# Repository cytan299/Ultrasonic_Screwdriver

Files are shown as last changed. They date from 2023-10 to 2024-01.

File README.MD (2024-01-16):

# Ultrasonic Screwdriver -- An improved DIY homemade Doctor Who Sonic Screwdriver

by C.Y. Tan 2023 and 2024

The Ultrasonic Screwdriver is an improved DIY homemade Doctor Who Sonic
Screwdrivers. I made this screwdriver that does actual, real
measurements rather than simply performing as a prop.

Ultrasonic Scewdriver

In my design, the heart of the Ultrasonic Screwdriver is the [ESP32-S3
reverse TFT Feather](https://www.adafruit.com/product/5691) made by
Adafruit. The ESP32-S3 contains dual cores running at 240 MHz with 4
MB Flash and 2 MB PSRAM of memory. Adafruit also added a colour 1.14
inch TFT display with 240x130 pixels. This makes the ESP32-S3 reverse
TFT Feather the ideal platform for the Ultrasonic Screwdriver because
it has enough horsepower and I/O to host multiple devices.  The
devices that the Ultrasonic Screwdriver contains are as follows:

* **Ultrasonic** range finder which makes it possible for me to call
  my screwdriver the Ultrasonic. The ultrasonic range finder is made
  by [MaxBotix](https://www.adafruit.com/product/983).
* **Torch** to light up the darkness or _alien dungeons_. Torch uses the [Neopixel 12x5050
  RGBW LEDs](https://www.adafruit.com/product/2851).
* **Thermal camera** which measures the temperature of objects using
  IR. The thermal camera is made by
  [Melexis](https://www.adafruit.com/product/4469). _It's great for
  scanning hot alien devices_.
* **WIFI** scanner that uses the built in [WIFI circuitry](https://learn.adafruit.com/esp32-s3-reverse-tft-feather/wifi-test) in the
  ESP32-S3 to _scan the air for alien radio transmissions_.
* **IR TV transmitter** uses the [RMT (remote control
  transceiver)](https://docs.espressif.com/projects/esp-idf/en/latest/esp32/api-reference/peripherals/rmt.html)
   built into the ESP32-S3 for controlling the TV using NEC codes. _Or
  to open alien doors_.
* **Sound** ESP32-S3 sends sound bytes to the [I2S 3W class D
  amplifer](https://www.adafruit.com/product/3006) for sound
  generation.
* **Ultrasonic zapper** combines the ultrasonic range finder that
  transmits ultrasound at 42 kHz in free-run mode, the Neopixel Ring
  flashing rainbow colours and the Ultrasound Screwdriver sound to
  scare animals or _blow up Daleks_ :)
  
Like many Doctor Who sonic screwdrivers, the Ultrasonic Screwdriver can
also be flicked or slid open. Unlike Doctor Who sonic screwdrivers that
_psychically_ connects with the Doctor, my rendition reveals the user
screen and control buttons after it is opened.

The only shortcoming of the Ultrasonic Screwdriver is that it does not
function as a screwdriver :)

And for completeness, I have also made a Charging Stand for the
Ultrasonic Screwdriver. It's a nice stand for the Ultrasonic
Screwdriver to rest and recharge.

Note: As of Jan 2024, the charging circuit has been upgraded to v2
which allows the Ultrasonic Screwdriver to be charged by simply
inserting it into the Charging Stand. All relevant files have been
updated to include this upgrade.

## Directory structure

* **openscad** The program _sonic_case.scad_ that generates the STL files for making the
  shell of the Ultrasonic Screwdriver.
* **STL** The STL files that were generated by the
  _sonic_case.scad_ and _sonic_stand.scad_. These files are used to 3D
  print the sonic shell and its charging stand using
slicer programs like [Ultimaker CURA](https://ultimaker.com/software/ultimaker-cura/).
* **ultrasonic_screwdriver** contains the ESP32-S3 source code that is
  compiled by the [Arduino IDE](https://www.arduino.cc/en/software)
  and programmed  into the ESP32-S3.
* **laser_cut** contains my unique badge and top plate that has
  decorations written in
  [Gallifreyan](https://shermansplanet.com/gallifreyan/guide.pdf).
* **circuit** The Ultrasonic Screwdriver and charging stand connection circuits.
* **howto** contains the build guide.	
* **bom** contains the bill of materials spreadsheet that
partially lists the parts that I had used to build the screwdriver.
* **pics** contains photos used for describing this repository.

## Movie

A summary of the features of the Ultrasonic Screwdriver can be found
on [youtube](https://youtu.be/zgtzh80xZCQ).

## Support

All the software have been successfully compiled with Arduino IDE 2.2.1.

This is unsupported software and hardware. Build at your own peril! :)

You can submit questions or bug reports using the
[issues](https://github.com/cytan299/Ultrasonic_Screwdriver/issues) tab 
and then clicking on **New Issue**.

Have fun!

## Copyright

All the software, documentation, hardware designs that I have written is
copyright 2023 C.Y. Tan.

All software is released under GPLv3.

All documentation is released under Creative Commons
Attribution-ShareAlike 3.0 Unported License or GNU Free
Documentation License, Version 1.3

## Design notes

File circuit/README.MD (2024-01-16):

# Ultrasonic Screwdriver schematic diagram

This is the schematic diagrams of the Ultrasonic Screwdriver and
charging circuit in Fritzing-like format. The [bill of materials
(BOM)](https://github.com/cytan299/Ultrasonic_Screwdriver/tree/main/bom)
file contains the parts that were used.

## Upgrade to v2

In v1, it is very clumsy to charge the Ultrasonic Screwdriver because
the bottom cover has to be unscrewed to reveal a charging plug. The
plug is then attached to the Charging Stand's socket for charging.  In
the upgraded version 2, the Ultrasonic Screwdriver can be charged by
inserting it into the Charging Stand.

These diagrams contain both the v1 and v2 circuits.

## Copyright

The schematic design of the Ultrasonic Screwdriver and charging
circuit is copyright 2023 C.Y. Tan and is released under under
Creative Commons Attribution-ShareAlike 3.0 Unported License. To view
a copy of this license, visit
http://creativecommons.org/licenses/by-sa/3.0/

The copyright for many of the parts used in this Fritzing-like schematic is held by Adafruit. Adafruit released the Adafruit Fritzing Libary under CC Attribution Share-Alike.

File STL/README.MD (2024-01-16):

# Parts for 3D printer

The subdirectories
* **sonic_case** contains the STL files that form the outer shell of
  the Ultrasonic screwdriver.
* **sonic_stand** contains the STL files that form the charging test stand.

## Copyright

All the STL files in subdirectories _sonic_case_ and _sonic_stand_ are
released under Creative Commons Attribution-ShareAlike 3.0 Unported
License.

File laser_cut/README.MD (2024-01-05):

# Laser cut parts

The subdirectories
* **badge** contains my unique badge that is mounted on the
  Ultrasonic screwdriver and its charging test stand.
* **top_plate** contains my unique top plate design that is mounted at
  the top of the charging test stand.

## Copyright

Both the _badge_single_v2.svg_ and _top_plate_ponoko1.svg_ are
released under Creative Commons Attribution-ShareAlike 3.0 Unported
License.

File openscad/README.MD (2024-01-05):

# OpenScad files

These [OpenScad](https://openscad.org/) files stored here generated
all the
[STL](https://github.com/cytan299/Ultrasonic_Screwdriver/tree/main/STL)
files that are loaded into a slicer program like the [Ultimaker
CURA](https://ultimaker.com/software/ultimaker-cura/) for 3D printing.

## Files
* **sonic_case.scad** The main source file that generates nearly all parts of the Ultrasonic Screwdriver case.
* **push_button.scad** The pushbutton that releases the spring to allow the inner case structure of the Ultrasonic Screwdriver to slide.
* **spring.scad** is the spring mechanism that holds the inner case
  structure open when it is extended out of the outer case.
* **sonic_stand.scad** is the source file that generates the
  Ultrasonic Screwdriver charging stand.
* **libscrew.scad** is the OpenScad [screw library](https://www.thingiverse.com/thing:1686322) written by R. Colyer. It is uploaded here for convenience.

## Copyright

All the software that I have written is copyright 2023 C.Y. Tan.

All software is released under GPLv3

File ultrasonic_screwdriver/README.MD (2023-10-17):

# ESP32 Ultrasonic Screwdriver Software

by C.Y. Tan 2023

This is the source code for the ESP32-S3 Ultrasonic Screwdriver
software. This software has been successfully compiled under Arduino
IDE 2.2.1. Instructions for enabling the Arduino IDE for compiling the
ESP32 can be found
[here](https://learn.adafruit.com/esp32-s3-reverse-tft-feather/arduino-ide-setup-2). This
program utilizes the dual core of the ESP32-S3 by splitting the tasks
between a master and a slave on each CPU. Communications between
master and slave is with [FreeTOS](https://docs.espressif.com/projects/esp-idf/en/latest/esp32/api-reference/system/freertos.html):
* **ultrasonic_screwdriver.ino** is the master program. It directly
controls
    * **Menu** system and user input.
	* **TV** IR control
    * **Sound** of the Ultrasonic Screwdriver.
	
From the user selection of the menu items, it sends messages to the slave program. The
tasks that the slave program executes are listed  below:
* **slave.ino** is the slave that listens to the master program and
  executes its commands for the following devices:
    * **Torch** on/off
	* **Thermal camera** display
	* **Sonic** ultrasound range finder display
	* **WIFI** scan and display
	* **Battery status** display.
	* **About** copyright and version display.
	
The following are the support programs used by both
_ultrasonic_screwdriver.ino_ and _slave.ino_:
* **IR_TX.cpp** and **IR_TX.hpp** contains the IR transmitter class that
  utilizes the ESP32-S3 onboard RMT (remote control transceiver) to
  produce NEC codes for TV control. The code here is for VIZIO TVs.
  Other codes for your TV is easily found in this
  [database](https://github.com/probonopd/irdb/tree/master).
* **audio.io** is the audio program that contains the Ultrasonic
  Screwdriver sound bytes that were created by me.
  
The following are programs that have been copied from the web and are
copyright by their respective authors. Here are the two programs that
are used:
* **ring_meter.ino** by Bodmer and is released under _CC BY-NC-SA 4.0
  Deed_ license. It is used for displaying the ultrasonic range finder
  results.
* **wheel.ino** by Adafruit and is released under _LGPL-3.0_
license. It is used for displaying the rainbow colours on the NeoPixel
  ring.

## Copyright

All the software that I have written is copyright 2023 C.Y. Tan.

All software is released under GPLv3.

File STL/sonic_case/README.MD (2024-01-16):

# Ultrasonic Screwdriver Case STL files

These STL files were created with [OpenScad](https://openscad.org/) from
the source code in
[openscad](https://github.com/cytan299/Ultrasonic_Screwdriver/tree/main/openscad). These
files are loaded into a slicer program like the [Ultimaker
CURA](https://ultimaker.com/software/ultimaker-cura/) for 3D printing.

## Infill

It is interesting that the best setting that I have found for the infill is
zigzag and not cubic. I wanted a strong shell and so I had to set the
fill fraction to be 50%. You should check that zigzag and 50% fill
works for you by examining the generated cross sections in your slicer
program.

## Upgrade to v2

In v1, the Ultrasonic Screwdriver is charged by unscrewing its base to
reveal a charging plug. The plug is then attached to the Charging
Stand's socket for charging.

In the upgraded version 2, the Ultrasonic Screwdriver can be charged
by inserting it into the Charging Stand. This upgrade will require the
following new STL files:

* **slip_adapter_v2.stl** The slip adapter that has space for the spring
  connector and the alignment recesses.
* **slip_cap_v2.stl** The slip cap that covers the bottom of the _slip
adapter v2_.

## Copyright

All the software that I have written is copyright 2023 C.Y. Tan.

All software is released under GPLv3.

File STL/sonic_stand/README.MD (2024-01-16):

# Ultrasonic Screwdriver Charging Stand STL files

These STL files were created with [OpenScad](https://openscad.org/)
from the source code in
[openscad](https://github.com/cytan299/Ultrasonic_Screwdriver/tree/main/openscad/sonic_stand.scad). These
files are loaded into a slicer program like the [Ultimaker
CURA](https://ultimaker.com/software/ultimaker-cura/) for 3D printing.

## Infill

Only top_plate_with_laser_plate.stl is printed with 10% gyroid with
transparent PLA. The remaining parts used an infill of 20% cubic. 

## Upgrade to v2

In v1, the Ultrasonic Screwdriver is charged by unscrewing its base to
reveal a charging plug. The plug is then attached to the Charging
Stand's socket for charging. 

In the upgraded version 2, the Ultrasonic Screwdriver can be charged
by inserting it into the Charging Stand. This upgrade will require the
following new STL file for the charging stand:

* **alignment_pegs.stl** This file contains the alignment pegs and the
  recess for the spring connector.

## Laser cut decoration

The laser cut decoration is in [laser_cut](https://github.com/cytan299/Ultrasonic_Screwdriver/tree/main/laser_cut)

## Copyright

All the software that I have written is copyright 2023 C.Y. Tan.

All software is released under GPLv3.

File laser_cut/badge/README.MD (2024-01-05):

# Badge

The file
* **badge_single_v2.svg** contains my unique badge design written in
  [Gallifreyan](https://shermansplanet.com/gallifreyan/guide.pdf) that
  is laser cut and mounted to the front of the Ultrasonic 
  Screwdriver and the charging stand.
  
The _badge_single_v2.svg_ can be sent to a laser cutting vendor
like [Ponoko](https://www.ponoko.com/) for laser cutting. The material that I had used is 1.5 mm thick
_Brushed Copper on Black Two Color Acrylic_. 

You can personalize the badge by modifying the svg file and
then laser cutting it.

## Copyright

The _badge_single_v2.svg_ is released under Creative Commons
Attribution-ShareAlike 3.0 Unported License.

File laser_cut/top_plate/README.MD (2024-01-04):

# Top plate

The file
* **top_plate_ponoko1.svg** contains my unique top plate design written in
  [Gallifreyan](https://shermansplanet.com/gallifreyan/guide.pdf) that
  is laser cut and mounted to the top of the Ultrasonic
  Screwdriver charging stand.
  
The _top_plate_ponoko1.svg_ can be sent to a laser cutting vendor
like [Ponoko](https://www.ponoko.com/) for laser cutting. The material
that I had used is the 0.5 mm copper on black adhesive-backed plastic.

You can personalize the badge by modifying the svg file and
then laser cutting it.

## Copyright

The _top_plate_ponoko1.svg_ is released under Creative Commons
Attribution-ShareAlike 3.0 Unported License.

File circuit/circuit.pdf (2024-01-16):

100Ω

IR diode
CQY37N

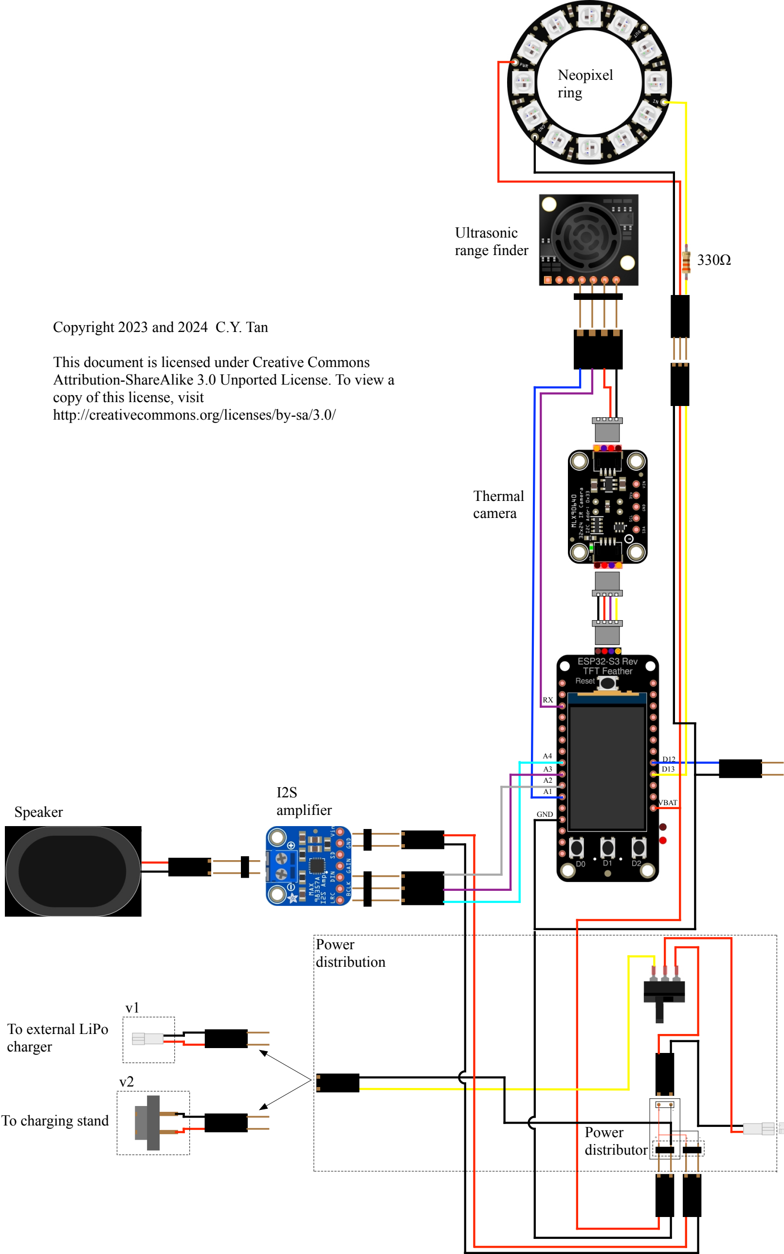
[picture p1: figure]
Neopixel ring; Ultrasonic range finder; Thermal camera; I2S amplifier; To external LiPo charger; Power distribution; GND; VBAT; Speaker; Power distributor; Copyright 2023 and 2024 C.Y. Tan; copy of this license, visit http://creativecommons.org/licenses/by-sa/3.0/; To charging stand

This document is licensed under Creative Commons Attribution-ShareAlike 3.0 Unported License. To view a

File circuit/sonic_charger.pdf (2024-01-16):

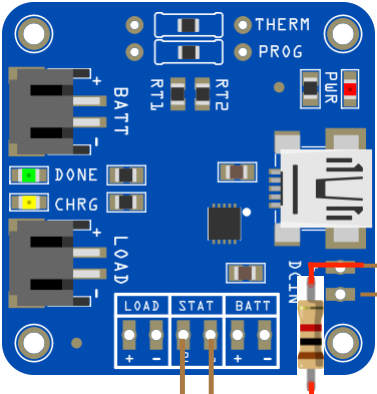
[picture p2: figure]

Red/Green LED
Common Anode

2.1 mm
power jack,
5 V in

Copyright 2023 and 2024 C.Y. Tan

This document is licensed under Creative Commons Attribution-ShareAlike 3.0 Unported License. To view a copy of this license, visit http://creativecommons.org/licenses/by-sa/3.0/

Adafruit LiIon/LiPoly
charger 1.2 V. Part
ID: 259

To ultrasonic
screwdriver

v1

v2

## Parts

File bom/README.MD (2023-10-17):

# Partial List of Materials

The bill of materials (bom) spreadsheet that I have uploaded here is
only a partial list. I have only listed the major parts that I had
ordered from both [Adafruit](https://www.adafruit.com) and
[Amazon](https://www.amazon.com). 

The parts that are missing are:
* **Paints** I did not list the paints that I had used because that's really up to
you how you'd want to paint it. 
* **3D filaments** I also did not list the 3D filaments that I had used. It's your
preference what you'll use for your 3D printer. 
    * For your reference, for the "clear" cover, I printed it with
      _SUNLU clear PLA filament 1.75 mm_. 
* **Sundries** Other sundries like sandpaper, masking tape etc. are also not included.

The bom.ods file is readable using [LibreOffice Calc](http://www.libreoffice.org).

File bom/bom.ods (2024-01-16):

Product # | Item | Quantity | Cost each | Cost | Comments | Vendor | Total Costs
5691 | ESP32-S3 reverse TFT feather | 1 | $24.95 | $24.95 |  | www.adafruit.com
3898 | Lithium Ion Polymer Battery Ideal For Feathers - 3.7V 400mAh | 1 | $6.95 | $6.95 |  |  | $245.48
4469 | Adafruit MLX90640 24x32 IR Thermal Camera Breakout (110 Degree FoV) | 1 | $74.95 | $74.95
983 | Maxbotix Ultrasonic Rangefinder - HRLV-EZ0 (HRLV-EZ0) | 1 | $36.50 | $36.50
3923 | Mini Oval Speaker - 8 Ohm 1 Watt | 1 | $1.95 | $1.95
1609 | Adafruit Perma-Proto Half-sized Breadboard PCB - Single | 1 | $0.00 | $0.00 | Free
2851 | Neopixel ring 12x505 RGBW leds | 1 | $9.50 | $9.50
3006 | I2S class D amplifier breakout | 1 | $5.95 | $5.95
259 | USB LiIon/LiPoly charger | 1 | $12.50 | $12.50
816 | 3x4 right angle male header | 1 | $2.95 | $2.95
1131 | JST-PH battery extension cable – 500 mm | 2 | $1.95 | $3.90
 | MEIYYJ 10 kinds of small multi-purpose M1 M1.2 M1.4 M1.7 Philips head micro self tapping electronic screws assortment | 1 | $6.99 | $6.99 |  | www.amazon.com
 | Glarks 635 pieces connector housing male/female connector 0.1” pitch pin headers etc. | 1 | $12.98 | $12.98
 | 150 pieces 3 pin 2 position 1P2T SPDT vertical micro slide switch 0.5 A 50V DC | 1 | $12.98 | $12.98
 | I2C Qwiic Cable Kit Stemma QT Wire for SparkFun Development Boards Sensor Board Breakout Breadboard 4 Pin Sh1.0 Connector | 1 | $9.99 | $9.99
CQY37N | Emitter IR 950 nm 100 mA radial | 1 | $0.43 | $0.43 |  | www.digikey.com
 | CHANZON 100 pcs 5mm Red & Green Diffused LED Diode Lights Common Anode | 1 | $6.99 | $0.07 | Only one is needed for the charging stand | www.amazon.com
 | HiLetgo 10pcs DC Power Supply Jack Socket Female Panel Mount Connector 3-Pin 5.5 x 2.1mm | 1 | $6.09 | $0.06 | Only one is needed for the charging stand
868-22-002-00-001101 | Mill-Max STD spring loaded connector (male) | 1 | $18.03 | $18.03 | Needed for v2 upgrade | www.mouser.com
868-10-002-00-012000 | Mill-Max 4 mm pitch Housings 4 mm pitch SLH solder cup (female) | 1 | $3.85 | $3.85 | Needed for v2 upgrade

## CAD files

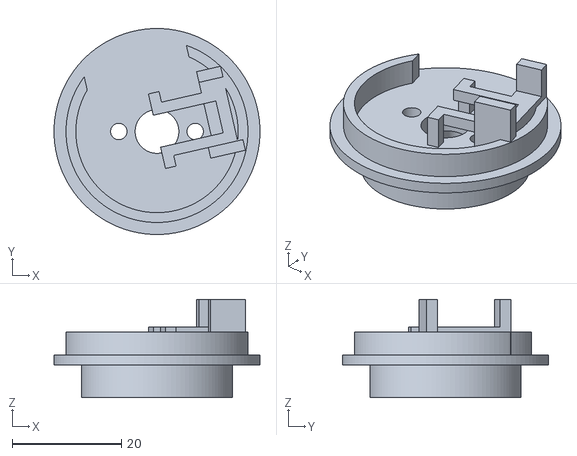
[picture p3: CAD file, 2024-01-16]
STL/sonic_case/slip_adapter_v2.stl
37.7 x 37.7 x 18.0

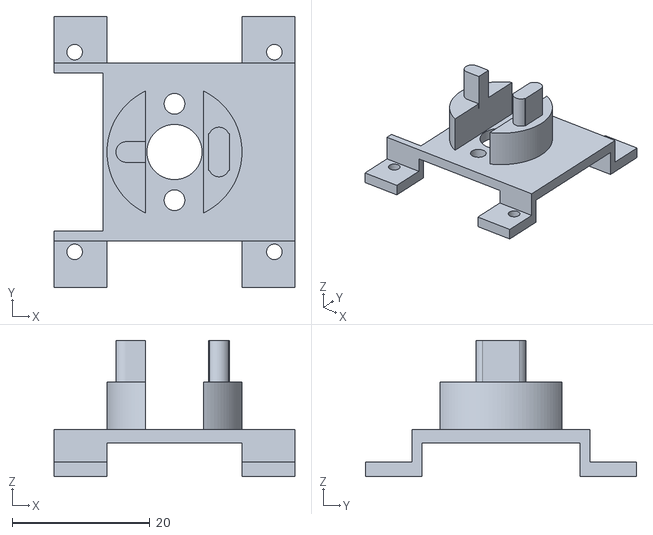
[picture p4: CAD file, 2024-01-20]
STL/sonic_stand/alignment_pegs.stl
35.0 x 39.4 x 19.8

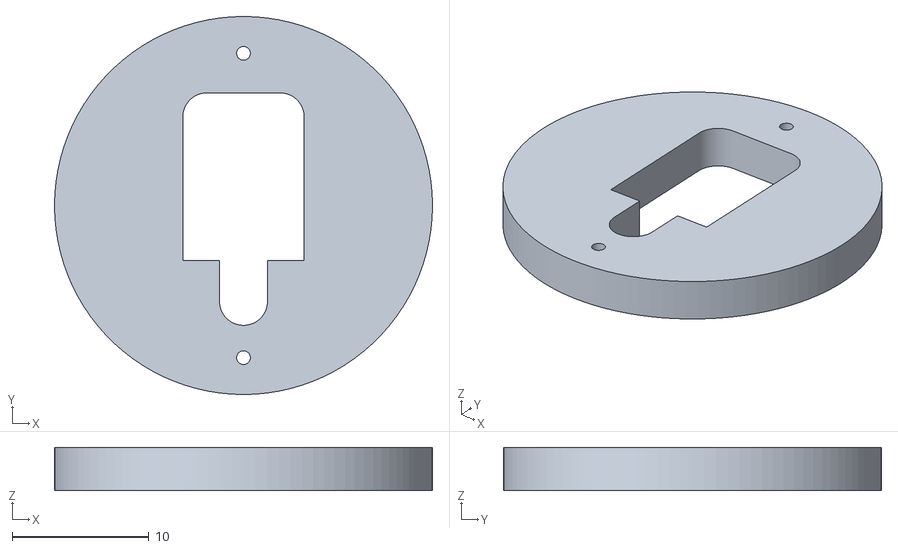
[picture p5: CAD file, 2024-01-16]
STL/sonic_case/slip_cap_v2.stl
27.6 x 27.6 x 3.15

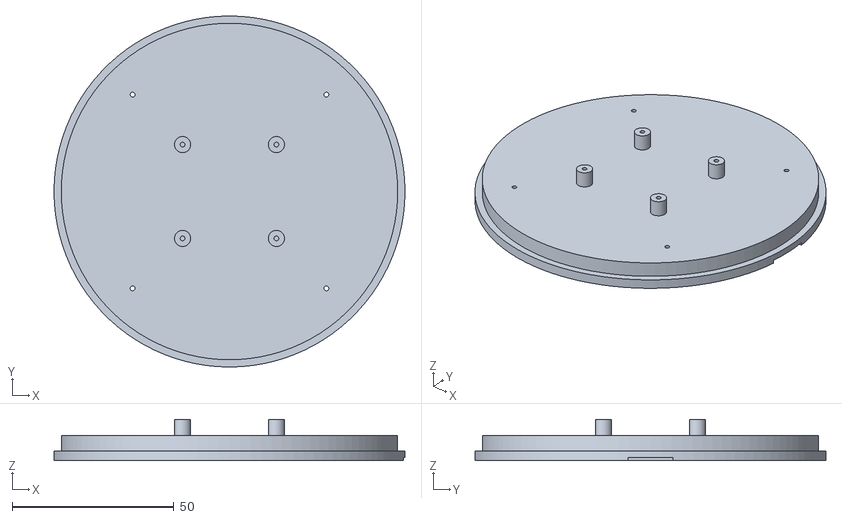
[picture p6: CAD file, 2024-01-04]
STL/sonic_stand/sonic_stand_cover.stl
108.5 x 108.5 x 12.8

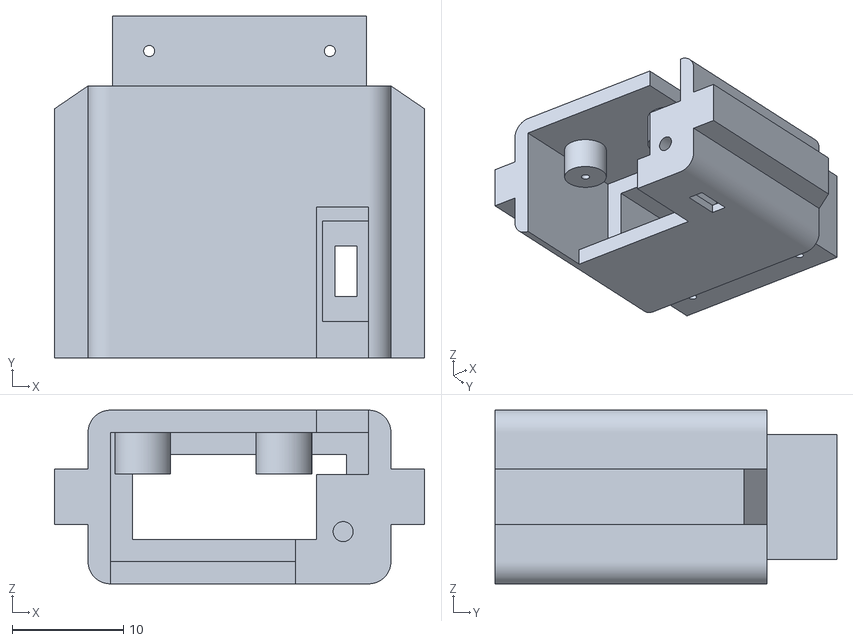
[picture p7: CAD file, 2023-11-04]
STL/sonic_case/tail_section.stl
33.3 x 30.8 x 15.6

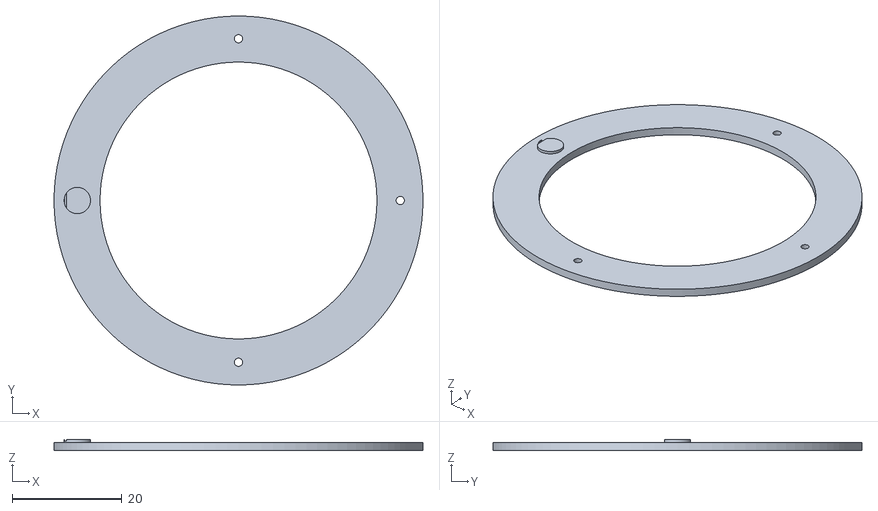
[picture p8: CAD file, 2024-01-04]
STL/sonic_stand/top_plate_with_laser_plate.stl
67.2 x 67.2 x 2.00

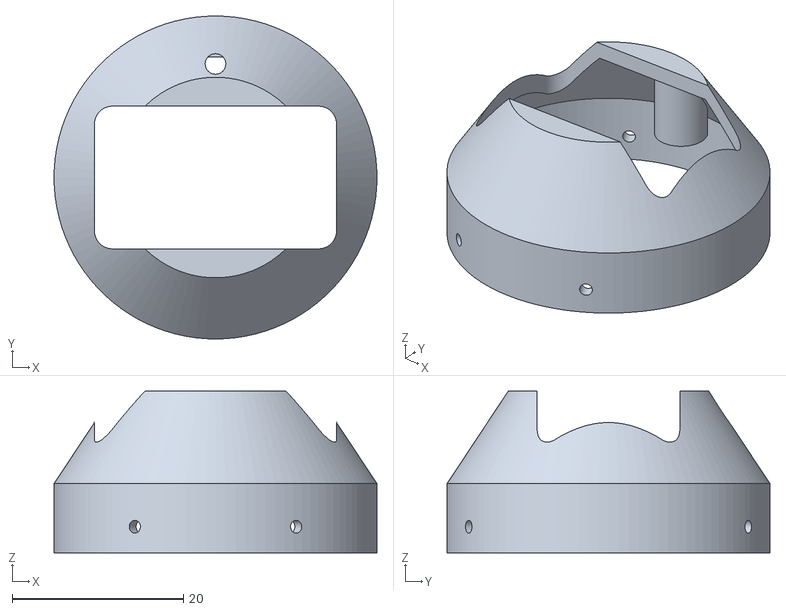
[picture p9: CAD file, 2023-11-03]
STL/sonic_case/cone.stl
37.7 x 37.7 x 18.9

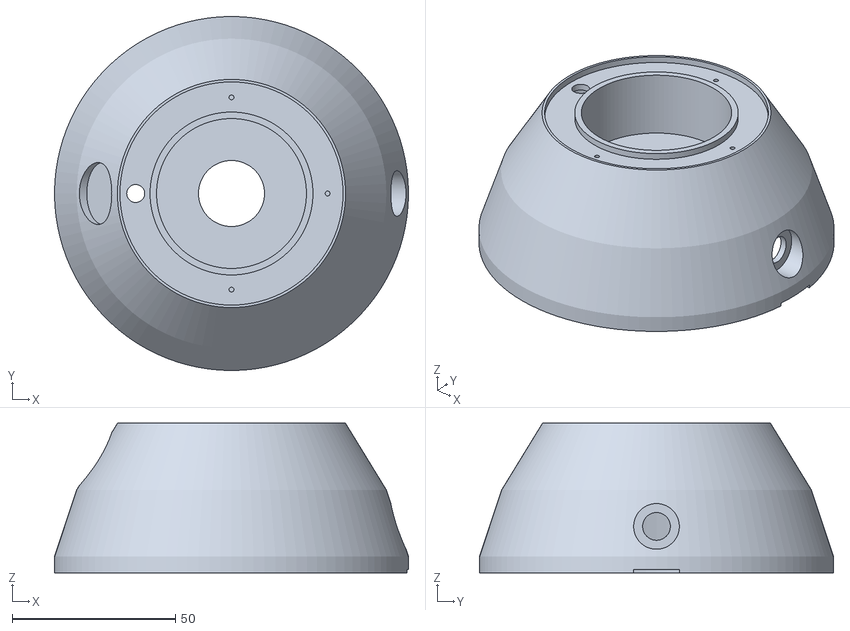
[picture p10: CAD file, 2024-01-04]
STL/sonic_stand/sonic_stand_top.stl
108.5 x 108.5 x 45.8

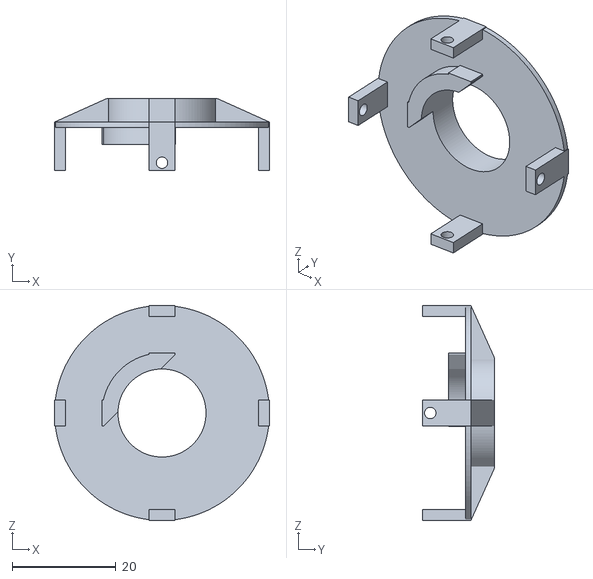
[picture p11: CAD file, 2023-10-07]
STL/sonic_case/upper_translucent_cover.stl
41.5 x 13.9 x 41.5

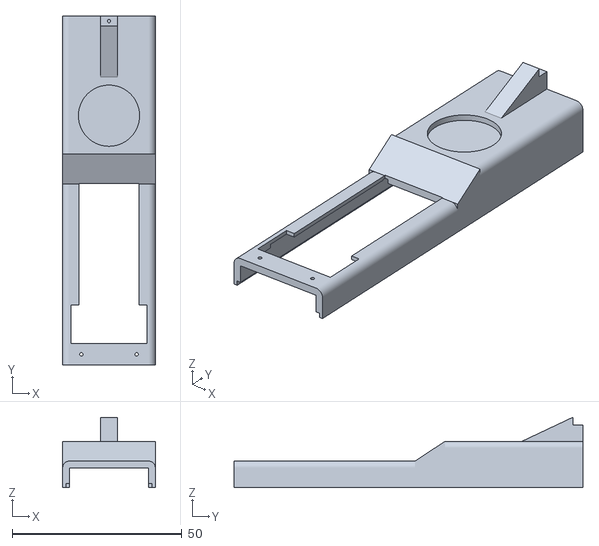
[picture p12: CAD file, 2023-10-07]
STL/sonic_case/inner_upper_case.stl
27.3 x 102.7 x 20.7

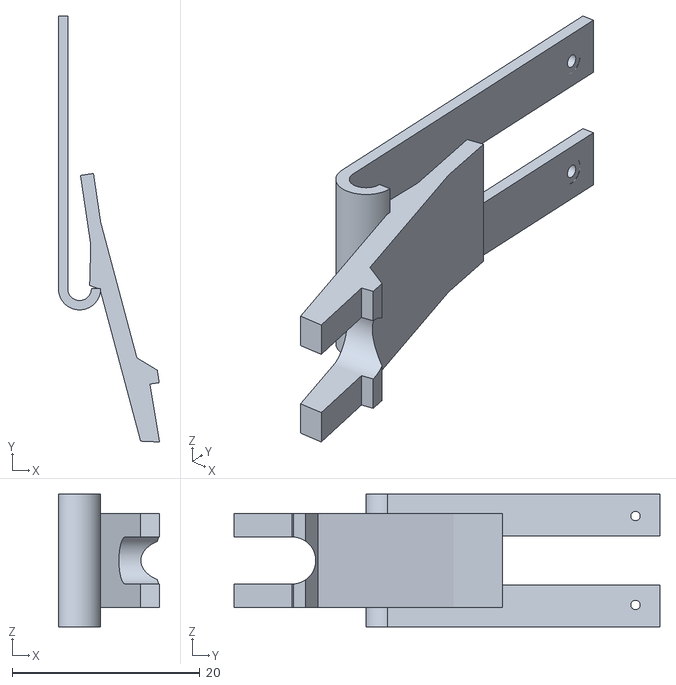
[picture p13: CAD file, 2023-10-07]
STL/sonic_case/spring.stl
10.8 x 45.4 x 14.1

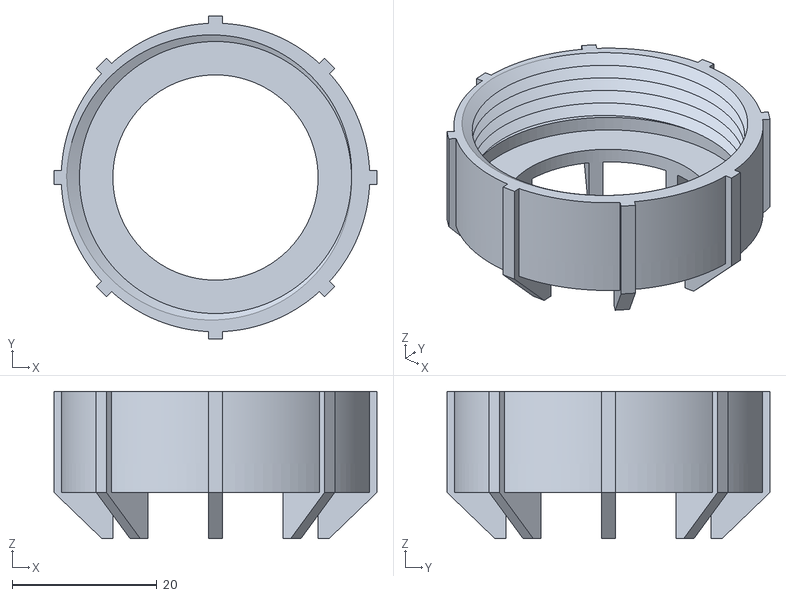
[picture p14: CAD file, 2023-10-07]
STL/sonic_case/endcap.stl
44.7 x 44.7 x 20.4

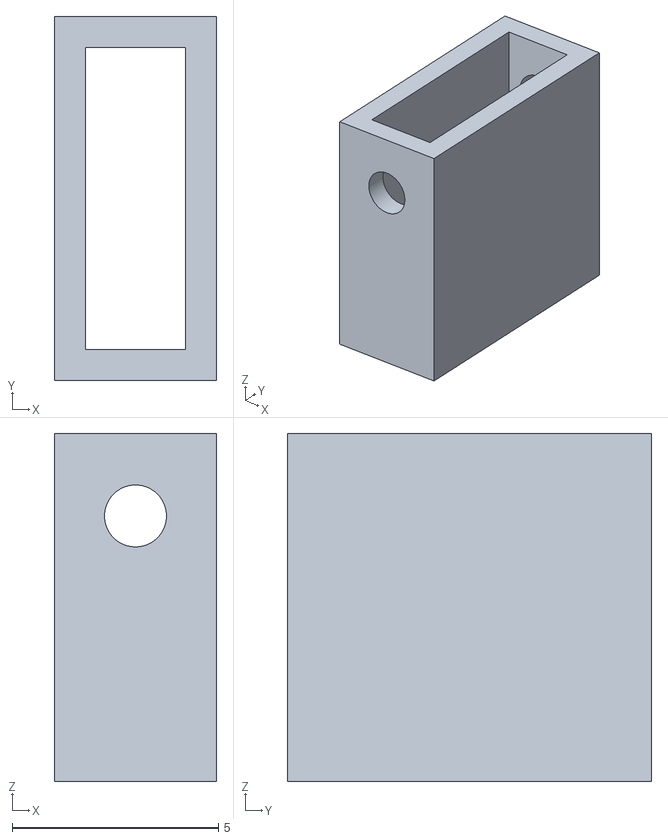
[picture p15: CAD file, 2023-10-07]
STL/sonic_case/switch_plug.stl
3.93 x 8.82 x 8.44

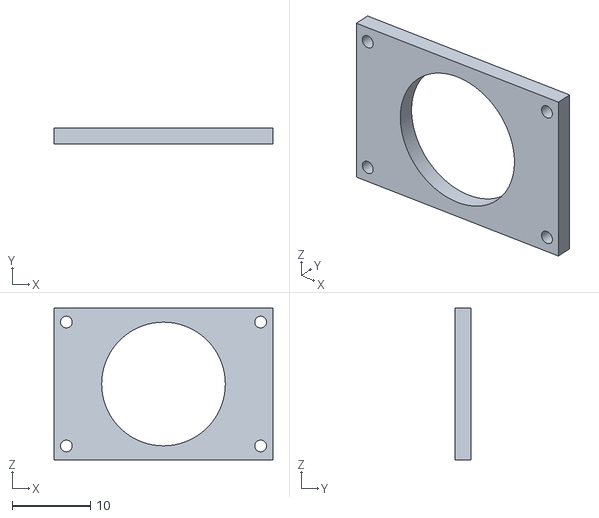
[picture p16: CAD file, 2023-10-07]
STL/sonic_case/speaker_holder.stl
28.0 x 2.00 x 19.4

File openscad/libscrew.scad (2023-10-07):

/**************************************************************/


// Created 2016-2017 by Ryan A. Colyer.
// This work is released with CC0 into the public domain.
// https://creativecommons.org/publicdomain/zero/1.0/
//
// https://www.thingiverse.com/thing:1686322
//
// v2.1


screw_resolution = 0.2;  // in mm


// Provides standard metric thread pitches.
function ThreadPitch(diameter) =
  (diameter <= 64) ?
    lookup(diameter, [
      [2, 0.4],
      [2.5, 0.45],
      [3, 0.5],
      [4, 0.7],
      [5, 0.8],
      [6, 1.0],
      [7, 1.0],
      [8, 1.25],
      [10, 1.5],
      [12, 1.75],
      [14, 2.0],
      [16, 2.0],
      [18, 2.5],
      [20, 2.5],
      [22, 2.5],
      [24, 3.0],
      [27, 3.0],
      [30, 3.5],
      [33, 3.5],
      [36, 4.0],
      [39, 4.0],
      [42, 4.5],
      [48, 5.0],
      [52, 5.0],
      [56, 5.5],
      [60, 5.5],
      [64, 6.0]
    ]) :
    diameter * 6.0 / 64;


// Provides standard metric hex head widths across the flats.
function HexAcrossFlats(diameter) =
  (diameter <= 64) ?
    lookup(diameter, [
      [2, 4],
      [2.5, 5],
      [3, 5.5],
      [3.5, 6],
      [4, 7],
      [5, 8],
      [6, 10],
      [7, 11],
      [8, 13],
      [10, 16],
      [12, 18],
      [14, 21],
      [16, 24],
      [18, 27],
      [20, 30],
      [22, 34],
      [24, 36],
      [27, 41],
      [30, 46],
      [33, 50],
      [36, 55],
      [39, 60],
      [42, 65],
      [48, 75],
      [52, 80],
      [56, 85],
      [60, 90],
      [64, 95]
    ]) :
    diameter * 95 / 64;

// Provides standard metric hex head widths across the corners.
function HexAcrossCorners(diameter) =
  HexAcrossFlats(diameter) / cos(30);


// Provides standard metric hex (Allen) drive widths across the flats.
function HexDriveAcrossFlats(diameter) =
  (diameter <= 64) ?
    lookup(diameter, [
      [2, 1.5],
      [2.5, 2],
      [3, 2.5],
      [3.5, 3],
      [4, 3],
      [5, 4],
      [6, 5],
      [7, 5],
      [8, 6],
      [10, 8],
      [12, 10],
      [14, 12],
      [16, 14],
      [18, 15],
      [20, 17],
      [22, 18],
      [24, 19],
      [27, 20],
      [30, 22],
      [33, 24],
      [36, 27],
      [39, 30],
      [42, 32],
      [48, 36],
      [52, 36],
      [56, 41],
      [60, 42],
      [64, 46]
    ]) :
    diameter * 46 / 64;

// Provides standard metric hex (Allen) drive widths across the corners.
function HexDriveAcrossCorners(diameter) =
  HexDriveAcrossFlats(diameter) / cos(30);

// Provides metric countersunk hex (Allen) drive widths across the flats.
function CountersunkDriveAcrossFlats(diameter) =
  (diameter <= 14) ?
    HexDriveAcrossFlats(HexDriveAcrossFlats(diameter)) :
    round(0.6*diameter);

// Provides metric countersunk hex (Allen) drive widths across the corners.
function CountersunkDriveAcrossCorners(diameter) =
  CountersunkDriveAcrossFlats(diameter) / cos(30);

// Provides standard metric nut thickness.
function NutThickness(diameter) =
  (diameter <= 64) ?
    lookup(diameter, [
      [2, 1.6],
      [2.5, 2],
      [3, 2.4],
      [3.5, 2.8],
      [4, 3.2],
      [5, 4.7],
      [6, 5.2],
      [7, 6.0],
      [8, 6.8],
      [10, 8.4],
      [12, 10.8],
      [14, 12.8],
      [16, 14.8],
      [18, 15.8],
      [20, 18.0],
      [22, 21.1],
      [24, 21.5],
      [27, 23.8],
      [30, 25.6],
      [33, 28.7],
      [36, 31.0],
      [42, 34],
      [48, 38],
      [56, 45],
      [64, 51]
    ]) :
    diameter * 51 / 64;


// This generates a closed polyhedron from an array of arrays of points,
// with each inner array tracing out one loop outlining the polyhedron.
// pointarrays should contain an array of N arrays each of size P outlining a
// closed manifold.  The points must obey the right-hand rule.  For example,
// looking down, the P points in the inner arrays are counter-clockwise in a
// loop, while the N point arrays increase in height.  Points in each inner
// array do not need to be equal height, but they usually should not meet or
// cross the line segments from the adjacent points in the other arrays.
// (N>=2, P>=3)
// Core triangles:
//   [j][i], [j+1][i], [j+1][(i+1)%P]
//   [j][i], [j+1][(i+1)%P], [j][(i+1)%P]
//   Then triangles are formed in a loop with the middle point of the first
//   and last array.
module ClosePoints(pointarrays) {
  function recurse_avg(arr, n=0, p=[0,0,0]) = (n>=len(arr)) ? p :
    recurse_avg(arr, n+1, p+(arr[n]-p)/(n+1));

  N = len(pointarrays);
  P = len(pointarrays[0]);
  NP = N*P;
  lastarr = pointarrays[N-1];
  midbot = recurse_avg(pointarrays[0]);
  midtop = recurse_avg(pointarrays[N-1]);

  faces_bot = [
    for (i=[0:P-1])
      [0,i+1,1+(i+1)%len(pointarrays[0])]
  ];

  loop_offset = 1;
  bot_len = loop_offset + P;

  faces_loop = [
    for (j=[0:N-2], i=[0:P-1], t=[0:1])
      [loop_offset, loop_offset, loop_offset] + (t==0 ?
      [j*P+i, (j+1)*P+i, (j+1)*P+(i+1)%P] :
      [j*P+i, (j+1)*P+(i+1)%P, j*P+(i+1)%P])
  ];

  top_offset = loop_offset + NP - P;
  midtop_offset = top_offset + P;

  faces_top = [
    for (i=[0:P-1])
      [midtop_offset,top_offset+(i+1)%P,top_offset+i]
  ];

  points = [
    for (i=[-1:NP])
      (i<0) ? midbot :
      ((i==NP) ? midtop :
      pointarrays[floor(i/P)][i%P])
  ];
  faces = concat(faces_bot, faces_loop, faces_top);

  polyhedron(points=points, faces=faces);
}



// This creates a vertical rod at the origin with external threads.  It uses
// metric standards by default.
module ScrewThread(outer_diam, height, pitch=0, tooth_angle=30, tolerance=0.4, tip_height=0, tooth_height=0, tip_min_fract=0) {

  pitch = (pitch==0) ? ThreadPitch(outer_diam) : pitch;
  tooth_height = (tooth_height==0) ? pitch : tooth_height;
  tip_min_fract = (tip_min_fract<0) ? 0 :
    ((tip_min_fract>0.9999) ? 0.9999 : tip_min_fract);

  outer_diam_cor = outer_diam + 0.25*tolerance; // Plastic shrinkage correction
  inner_diam = outer_diam - tooth_height/tan(tooth_angle);
  or = (outer_diam_cor < screw_resolution) ?
    screw_resolution/2 : outer_diam_cor / 2;
  ir = (inner_diam < screw_resolution) ? screw_resolution/2 : inner_diam / 2;
  height = (height < screw_resolution) ? screw_resolution : height;

  steps_per_loop_try = ceil(2*3.14159265359*or / screw_resolution);
  steps_per_loop = (steps_per_loop_try < 4) ? 4 : steps_per_loop_try;
  hs_ext = 3;
  hsteps = ceil(3 * height / pitch) + 2*hs_ext;

  extent = or - ir;

  tip_start = height-tip_height;
  tip_height_sc = tip_height / (1-tip_min_fract);

  tip_height_ir = (tip_height_sc > tooth_height/2) ?
    tip_height_sc - tooth_height/2 : tip_height_sc;

  tip_height_w = (tip_height_sc > tooth_height) ? tooth_height : tip_height_sc;
  tip_wstart = height + tip_height_sc - tip_height - tip_height_w;


  function tooth_width(a, h, pitch, tooth_height, extent) =
    let(
      ang_full = h*360.0/pitch-a,
      ang_pn = atan2(sin(ang_full), cos(ang_full)),
      ang = ang_pn < 0 ? ang_pn+360 : ang_pn,
      frac = ang/360,
      tfrac_half = tooth_height / (2*pitch),
      tfrac_cut = 2*tfrac_half
    )
    (frac > tfrac_cut) ? 0 : (
      (frac <= tfrac_half) ?
        ((frac / tfrac_half) * extent) :
        ((1 - (frac - tfrac_half)/tfrac_half) * extent)
    );


  pointarrays = [
    for (hs=[0:hsteps])
      [
        for (s=[0:steps_per_loop-1])
          let(
            ang_full = s*360.0/steps_per_loop,
            ang_pn = atan2(sin(ang_full), cos(ang_full)),
            ang = ang_pn < 0 ? ang_pn+360 : ang_pn,

            h_fudge = pitch*0.001,

            h_mod =
              (hs%3 == 2) ?
                ((s == steps_per_loop-1) ? tooth_height - h_fudge : (
                 (s == steps_per_loop-2) ? tooth_height/2 : 0)) : (
              (hs%3 == 0) ?
                ((s == steps_per_loop-1) ? pitch-tooth_height/2 : (
                 (s == steps_per_loop-2) ? pitch-tooth_height + h_fudge : 0)) :
                ((s == steps_per_loop-1) ? pitch-tooth_height/2 + h_fudge : (
                 (s == steps_per_loop-2) ? tooth_height/2 : 0))
              ),

            h_level =
              (hs%3 == 2) ? tooth_height - h_fudge : (
              (hs%3 == 0) ? 0 : tooth_height/2),

            h_ub = floor((hs-hs_ext)/3) * pitch
              + h_level + ang*pitch/360.0 - h_mod,
            h_max = height - (hsteps-hs) * h_fudge,
            h_min = hs * h_fudge,
            h = (h_ub < h_min) ? h_min : ((h_ub > h_max) ? h_max : h_ub),

            ht = h - tip_start,
            hf_ir = ht/tip_height_ir,
            ht_w = h - tip_wstart,
            hf_w_t = ht_w/tip_height_w,
            hf_w = (hf_w_t < 0) ? 0 : ((hf_w_t > 1) ? 1 : hf_w_t),
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

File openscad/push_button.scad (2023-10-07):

/*

    push_button.scad is the code to generate push button for the ultrasonic
    screwdriver
    
    Copyright (C) 2023  C.Y. Tan
    Contact: cytan299@yahoo.com

    This file is part of the ultrasonic screwdriver distribution.

    push_button.scad is free software: you can redistribute it and/or modify
    it under the terms of the GNU General Public License as published by
    the Free Software Foundation, either version 3 of the License, or
    (at your option) any later version.

    push_button.scad is distributed in the hope that it will be useful,
    but WITHOUT ANY WARRANTY; without even the implied warranty of
    MERCHANTABILITY or FITNESS FOR A PARTICULAR PURPOSE.  See the
    GNU General Public License for more details.

    You should have received a copy of the GNU General Public License
    along with push_button.scad.  If not, see <http://www.gnu.org/licenses/>.

*/

$fn=100;

screw_r = 2.5; // mm, radius of the screw
//screw_len = 5.2976+1; // mm, length of the screw
screw_len = 5.2976; // mm, length of the screw
screw_pitch = 0.75; // pitch of the screw

interface_r = 9.8/2; // mm, the interface between the plunger radius
interface_h = 1; // mm, the height of the interface

plunger_h = 1.5125; // mm, the height of the plunger
plunger_r1 = 2.5; //mm, the part that touches the spring
plunger_r2 = interface_r; //mm, the part the touches the interface


button_r = 9.8/2; // mm, the radius of the button
button_h = 4.5; // mm, the height of the button
button_thread_len = 2.5; // mm, the length of the thread

module make_plunger()
{

  // make the screw threads
  translate([0,0,plunger_h]){
    RodStart(diameter=interface_r*2, height=interface_h, thread_len=screw_len, thread_diam=screw_r*2, thread_pitch= screw_pitch);
  }

  // make the plunger
  cylinder(r1=plunger_r1, r2 = plunger_r2, h=plunger_h, center=false);
}

module make_button()
{
  dtol = 0.0;
    
  RodEnd(diameter = button_r*2, height=button_h, thread_len = button_thread_len, thread_diam = 2*screw_r + dtol, thread_pitch=screw_pitch);  
}


/*
  Entry point
*/


 translate([0, -7, 0]){
   make_plunger();
 }
  

  translate([0, 7, 0]){
    make_button();
  }



include <libscrew.scad>

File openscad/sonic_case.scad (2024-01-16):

/*
    sonic_case.scad is the code to generate a case for a sonic
    screwdriver
    
    Copyright (C) 2023  C.Y. Tan
    Contact: cytan299@yahoo.com

    This file is part of the CP4 and CP5 dust cover distribution.

    sonic_case.scad is free software: you can redistribute it and/or modify
    it under the terms of the GNU General Public License as published by
    the Free Software Foundation, either version 3 of the License, or
    (at your option) any later version.

    sonic_case.scad is distributed in the hope that it will be useful,
    but WITHOUT ANY WARRANTY; without even the implied warranty of
    MERCHANTABILITY or FITNESS FOR A PARTICULAR PURPOSE.  See the
    GNU General Public License for more details.

    You should have received a copy of the GNU General Public License
    along with sonic_case.scad.  If not, see <http://www.gnu.org/licenses/>.

*/

$fn=100;

/***************************************
	Inner tube definitions
****************************************/

// inside dimensions of the lower case
IBox_len_x = 23.26; // mm

IBox_total_y = 127.1558; //mm, total length of the internal size
IBox_len_y1a = 40.6; // mm, length of case closest to wall
IBox_len_y0a = 77.7558;//86.5558; // mm, length of case closest to USB

IBox_len_y0 = 109.0558;// mm, distance from ref (0,0) to the bottom of the wing
IBox_len_y1 = IBox_total_y - IBox_len_y0; //18.1 //mm, remining distance


IBox_len_y = IBox_total_y; // mm

IBox_len_z = 5.825; //mm

// inside dimensions of the lower case

IBox_len_z0 = IBox_len_z; //mm
IBox_len_z1 = 11.65; //mm

/*********/

// inside dimensions of the upper case
IUBox_len_x = IBox_len_x; // mm

IUBox_len_y0 = IBox_len_y0; // mm
IUBox_len_y1 = IBox_len_y1; //mm

IUBox_len_y = IUBox_len_y0 + IUBox_len_y1; // mm

IUBox_len_z = IBox_len_z;//2*IBox_len_z1-IBox_len_z; //mm, (total inside z = 2*IBox_len_z1) - (lower box z = IBox_len_z)

// inside dimensions of the upper case
IUBox_len_z0 = IUBox_len_z; //mm
IUBox_len_z1 = IBox_len_z1;

IUBox_total_y = IBox_total_y;
IUBox_len_y0a = IBox_len_y0a; // mm, length of case closest to USB
IUBox_len_y1a = IBox_len_y1a; // mm, length of case closest to LED


// outside dimensions of lower box

Box_wall_t = 2; //mm, wall thickness

Box_len_x = IBox_len_x + 2*Box_wall_t; //mm
Box_len_y = IBox_len_y + Box_wall_t; //mm
Box_len_z = IBox_len_z + 1*Box_wall_t; //mm

Box_len_z0 = IBox_len_z0 + Box_wall_t; //mm
Box_offset_z0 = IBox_len_z1 - IBox_len_z; //mm, the box at the USB end has a z offset

Box_len_y1 = IBox_len_y1 + Box_wall_t; //mm
Box_len_z1 = IBox_len_z1 + Box_wall_t; //mm

Box_mid_x_pos = Box_len_x/2.0;



// outside dimensions of the upper

UBox_wall_t = 2; //mm, wall thickness

UBox_len_x = IUBox_len_x + 2*UBox_wall_t; //mm
UBox_len_y = IUBox_len_y + UBox_wall_t; //mm
UBox_len_z = IUBox_len_z + 1*UBox_wall_t; //mm

UBox_len_z0 = IUBox_len_z0 + 1*Box_wall_t; // mm
UBox_len_z1 = IUBox_len_z1 + 1*Box_wall_t; // mm


UBox_offset_z0 = Box_offset_z0; //IUBox_len_z1 - IUBox_len_z; //mm, the box at the USB end has a z offset

UBox_mid_x_pos = UBox_len_x/2.0;



//end wall
End_Wall_len_z = 22.84;  //mm

//screw holes
screw_r = 1.0; //mm

// pillar definitions
  // A is for feather

  pillarA_len_z = 9.51; //mm
  pillarA_width  = 3.6; // mm
  pillarA_hole_r = 0.5; //mm

  // B is for the camera
  pillarB_len_z = 4.26; //mm
  pillarB_r = 2.5; // mm
  pillarB_hole_r = 0.5; //mm

  // C is for audio amp
  pillarC_len_z = 1.5; //mm
  pillarC_r = 2.5; // mm
  pillarC_hole_r = 0.5; //mm

  // D is for sonic
  pillarD_len_z = 4.26; //mm
  pillarD_r = 2.5; // mm
  pillarD_hole_r = screw_r; //mm

  //E is for i2s
  pillarE_len_z = 3.75; //mm
  pillarE_r = 2.5; // mm
  pillarE_hole_r = 0.5; //mm
  



// camera hole radius
camera_r = 5.1; //4.80; //mm

// ultrasound hole radius
ultrasound_r = 8.5; //mm
ultrasound_h = 8.9; //mm, height of the tube
ultrasound_tube_r = 10.66;
ultrasound_z_pos = IBox_len_z1;


// LED ring
LED_outer_r = 18.56; //mm
LED_inner_r = 11.6; //mm
LED_inner_h = 3.35; //mm
LED_top_r = 20.76; // mm the top transparent cover
LED_top_h = 1; // mm thickness of the transparent cover

LED_pcboard_h = 3.35; //mm


// wing thickness
wing_thickness = 5; // mm

// Screen size
Screen_len_x =17.7; //mm
Screen_len_y = 41.6; //36.794; //mm


// 3 button access hole size
button3_len_dx = 1; // small correction for strength
button3_len_x = 23.36-button3_len_dx; //mm
button3_len_y = 11.343; //mm

// push button hole size
pushbutton_r = 5; // mm
pushbutton_z = 67.1679; //mm

// spring holder size
spring_holder_len_x = 23.2588; // mm
spring_holder_len_y = 24.9735; // mm




/***************************************
	Outer tube definitions
****************************************/


// inside dimensions of outer tube
O_IBox_r0 = 33.7/2; //mm, closest to the USB port
O_IBox_r1 = 22.05/2; //mm, closes to the ultrasonic

O_IBox_y0 = 108.9558; // mm, the longest part closest to the USB port to the start of the cone
O_IBox_y1 = 8.8; // mm, the shortest part closest to ultrasonic
O_IBox_total_y = O_IBox_y0 + O_IBox_y1;

// outside dimensions of outer tube
O_Box_r0 = O_IBox_r0 + Box_wall_t; //mm, closest to the USB port
O_Box_r1 = O_IBox_r1 + Box_wall_t; //mm, closes to the ultrasonic

O_Box_y0 = O_IBox_y0 + 0*Box_wall_t; //mm, the longest part closest to USB port. Note no wall at the USB end.
O_Box_y1 = O_IBox_y1 + Box_wall_t;// mm, the shortest part closest to ultrasonic

// battery compartment
battery_r = 17/2.0;//mm
battery_wall_t = Box_wall_t; //mm

battery_tilt_angle = 12.8835; // deg. rotation angle for battery compartment



/****
  Cone definitions
*****/
cone_tab_len_z = 8.0979;

/******
  End cap
 *****/

// end cap

endcap_thread_r = O_Box_r0 + 1; // mm, radius of the thread
endcap_thread_h = 10; //mm, height of the thread
endcap_thread_p = 2; // mm, thread pitch
endcap_outer_dr = 0.5; //mm, move in the outer radius a little for the vertical wings
endcap_outer_r = endcap_thread_r+Box_wall_t - endcap_outer_dr; //mm, outer radius of the endcap

endcap_slip_r = O_IBox_r0 + Box_wall_t;
endcap_slip_hole_r = 14; //mm, outer radius of the slip adapter
endcap_slip_h = 7.91/2; //mm height of the tube

endcap_hole_r = 1;
endcap_pos_z = 5;


/***************************************
	tail
****************************************/

Tail_total_len_y = 30.7558;  // mm, totail length  of the tail including tab
Tail_tab_len = 6.2776; // mm


/*****
  alignment parts
****/      

alignment_screw_r = 0.75;
alignment_screw_x = 0;
alignment_screw_y = 11.1087;

// the round hole
alignment_hole_y = -7.0003;
alignment_cylinder_h = endcap_slip_h+Box_wall_t;

slip_power_hole_r = 7.998/2.0; //mm
alignment_peg_r = 3.5/2.0; //mm
spring_connect_z_offset = 1.5012;

alignment_rect_y = 6.4674;
alignment_rect_w0 = alignment_peg_r;
alignment_rect_l0 = 5.3578;

alignment_rect_w1 = 2.3743;
alignment_rect_l1 = alignment_rect_l0 + 2*alignment_peg_r;




module make_lower_box0()
{
  // this is the box that is closest to the USB port

  Box_len_y0a = IBox_len_y0a;

  translate([0,0,Box_offset_z0]){
    difference(){  
      union(){
	difference(){
          // make outside cube
	  union(){
	    cube([Box_len_x, Box_len_y0a, Box_len_z], center= false);

	  }

	  // remove the edge to that I can round it later
	  union(){
	    translate([-Box_wall_t, -Box_wall_t, 0])	  
	      cube([2*Box_wall_t, Box_len_y + 2*Box_wall_t, Box_wall_t], center=false);
	    translate([IBox_len_x+Box_wall_t, -Box_wall_t, 0])
	      cube([2*Box_wall_t, Box_len_y + 2*Box_wall_t, Box_wall_t], center=false);
	  }
	}

        // add in the round edges
        translate([Box_wall_t, 0, Box_wall_t]){
	  rotate([-90,0,0]){
            cylinder(h=Box_len_y0a,r=2, center=false);
	  }
        }
      
        translate([IBox_len_x+Box_wall_t, 0, Box_wall_t]){
	  rotate([-90,0,0]){
            cylinder(h=Box_len_y0a,r=2, center=false);
	  }
	}
      }

      // remove inside
      translate([Box_wall_t, -Box_wall_t, Box_wall_t])
        cube([IBox_len_x , IBox_len_y+4*Box_wall_t , IBox_len_z + 4*Box_wall_t],
	     center=false);

    }
  }
  
}

module make_lower_middle_box()
{
  union(){
    // make angled wall
    translate([Box_len_x/2.0,IBox_len_y0a,Box_offset_z0+Box_wall_t/2.0]){
      //get the angled slide to be into the correct orientation
      rotate([0,-90,0]){
	translate([-6.825,0,-Box_len_x/2.0]){
	  linear_extrude(height=Box_len_x, center=false){
	    polygon(points=[[5.825,0.00],[7.825, 0.0],[2.00,8.80],[0,8.8]]);
	  }
	}
      }
    }

    //make left side walls
    translate([Box_wall_t,IBox_len_y0a,Box_len_z1]){
      rotate([0,-90,0]){
        translate([-13.65//-10.7375,0
		   ,-0*Box_wall_t/2.0]){
          linear_extrude(height=Box_wall_t, center=false){
	    polygon(points=[[7.825,0.00],[13.65, 0.0],[13.65,8.80],[0,8.8]]);  

	  }
        }
      }
    }
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

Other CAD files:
STL/sonic_case/push_button.stl
STL/sonic_case/slipcap.stl
STL/sonic_case/outer_upper_case.stl
STL/sonic_case/outer_lower_case.stl
openscad/sonic_stand.scad
STL/sonic_case/inner_lower_case.stl
STL/sonic_case/slip_adapter.stl
STL/sonic_case/spring_crossbar.stl
openscad/spring.scad

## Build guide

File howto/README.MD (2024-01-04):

# How to build the Ultrasonic Screwdriver

I have written 

* **assembly.pdf** This guide tells you how I assembled the
  screwdriver and its stand. I think I have covered most of the details.

## Copyright

These documents are copyright 2023 C.Y. Tan and released under
Creative Commons Attribution-ShareAlike 3.0 Unported License.

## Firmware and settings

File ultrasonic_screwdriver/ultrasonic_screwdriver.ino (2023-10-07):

/*$Id$*/
/*
    ultrasonic_screwdriver is the controller code for the Adafruit
    ESP32-S3 reverse TFT Feather
    Copyright (C) 2023 C.Y. Tan
    Contact: cytan299@yahoo.com

    This file is part of ultrasonic_screwdriver

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
    You should have received a copy of the GNU General Public License
    along with ultrasonic_screwdriver.  If not, see
    <http://www.gnu.org/licenses/>.

*/

/* operating system header files (use <> for make depend) */


#include  <Arduino.h>
#include <queue.h>

/* general system header files (use "" for make depend) */


/*

   For the graphics display
*/

#include <Adafruit_GFX.h>
#include <Adafruit_ST7789.h>
#include <Adafruit_MLX90640.h>
#include <Adafruit_NeoPixel.h>

#include "AudioTools.h"

#include <menu.h>
#include <menuIO/adafruitGfxOut.h>



/*
  For the menu
*/

#include <menuIO/altKeyIn.h>
#include <menuIO/chainStream.h>

#ifdef MENU_DEBUG
#include <menuIO/serialOut.h>
#include <menuIO/serialIn.h>
#endif 

using namespace Menu;

#define BTN_SEL 1	// Select button
#define BTN_UP 0 // Up
#define BTN_DOWN 2 // Down


/*
  Neopixel ring
*/


#define NEOPIXEL_PIN	13
#define NEOPIXEL_NUM_PIXELS	12
Adafruit_NeoPixel neopixel_ring = Adafruit_NeoPixel(NEOPIXEL_NUM_PIXELS,
						    NEOPIXEL_PIN,
						    NEO_RGBW);



/*
  The TFT
*/

Adafruit_ST7789 gfx = Adafruit_ST7789(TFT_CS, TFT_DC, TFT_RST);

uint16_t displayPixelWidth, displayPixelHeight;

/*
 The thermal camera
*/

Adafruit_MLX90640 mlx;

/*
  The ultrasound sonic
*/

#define ULTRASONIC_EN	A1

/*
  The IR diode
*/

#include "IR_TX.hpp"

IR_TX ir_tx(RMT_CHANNEL_0, GPIO_NUM_12);

/*
  For sonic screwdriver sound
*/

extern GeneratorFromArray<int16_t> sonicdriver_wave;
extern AudioInfo info;
extern StreamCopy copier;



/*
  Setting up the menu
*/

bool is_poll_BTN_SEL = false;
bool is_poll_BTN_DESEL = false;

bool is_torch_on = false;
bool is_sound_on = true;


typedef enum {M_TORCH, M_THERMAL, M_SONIC,
	      M_ZAPPER, M_TV, M_WIFI, M_BATTERY,
	      M_SOUND, M_ABOUT, M_DONE,
	      M_BUSY} MessageID;

MessageID s_state = M_DONE;

/**********************************************************************
  Defines
 **********************************************************************/  
//#define DEBUG

/**********************************************************************
  Setting up the colour definitions of the TFT
 **********************************************************************/  


#define ST77XX_GRAY RGB565(128,128,128)

const colorDef<uint16_t> colors[6] MEMMODE={
  {{(uint16_t)ST77XX_BLACK,(uint16_t)ST77XX_BLACK}, {(uint16_t)ST77XX_BLACK, (uint16_t)ST77XX_BLUE,  (uint16_t)ST77XX_BLUE}},//bgColor
  {{(uint16_t)ST77XX_GRAY, (uint16_t)ST77XX_GRAY},  {(uint16_t)ST77XX_WHITE, (uint16_t)ST77XX_WHITE, (uint16_t)ST77XX_WHITE}},//fgColor
  {{(uint16_t)ST77XX_WHITE,(uint16_t)ST77XX_BLACK}, {(uint16_t)ST77XX_YELLOW,(uint16_t)ST77XX_YELLOW,(uint16_t)ST77XX_RED}},//valColor
  {{(uint16_t)ST77XX_WHITE,(uint16_t)ST77XX_BLACK}, {(uint16_t)ST77XX_WHITE, (uint16_t)ST77XX_YELLOW,(uint16_t)ST77XX_YELLOW}},//unitColor
  {{(uint16_t)ST77XX_WHITE,(uint16_t)ST77XX_GRAY},  {(uint16_t)ST77XX_BLACK, (uint16_t)ST77XX_BLUE,  (uint16_t)ST77XX_WHITE}},//cursorColor
  {{(uint16_t)ST77XX_WHITE,(uint16_t)ST77XX_YELLOW},{(uint16_t)ST77XX_BLUE,  (uint16_t)ST77XX_RED,    (uint16_t)ST77XX_RED}},//titleColor
};


/**********************************************************************
NAME

	menu_item_* - All the callbacks used by the Menu system
		   
SYNOPSIS

	menu_item_* are all the callbacks used by the Menu system.
	
AUTHOR
	C.Y. Tan

REVISION
	$Revision$

SEE ALSO

**********************************************************************/


result menu_item_camera_status(){

  is_poll_BTN_SEL = !is_poll_BTN_SEL;
  
  
#ifdef DEBUG
  Serial.print("Camera ");
  Serial.println(is_poll_BTN_SEL? "activated": "de-activated");
#endif

  if(is_poll_BTN_SEL){
    s_state = M_THERMAL;
  }
  else {
    s_state = M_DONE;
  }

  return proceed;
}


result menu_item_sonic_status(){

  is_poll_BTN_SEL = !is_poll_BTN_SEL;
  
  
#ifdef DEBUG
  Serial.print("Sonic ");
  Serial.println(is_poll_BTN_SEL? "activated": "de-activated");
#endif

  if(is_poll_BTN_SEL){
    s_state = M_SONIC;
  }
  else {
    s_state = M_DONE;
  }

  return proceed;
}

result menu_item_zapper_status(){

  is_poll_BTN_SEL = !is_poll_BTN_SEL;
  
  
#ifdef DEBUG
  Serial.print("Zapper ");
  Serial.println(is_poll_BTN_SEL? "activated": "de-activated");
#endif

  if(is_poll_BTN_SEL){
    s_state = M_ZAPPER;
  }
  else {
    s_state = M_DONE;
  }

  return proceed;
}

result menu_item_WIFI_status(){

  is_poll_BTN_SEL = !is_poll_BTN_SEL;
  
  
#ifdef DEBUG
  Serial.print("WIFI scan ");
  Serial.println(is_poll_BTN_SEL? "activated": "de-activated");
#endif

  if(is_poll_BTN_SEL){
    s_state = M_WIFI;
  }
  else {
    s_state = M_DONE;
  }

  return proceed;
}


result menu_item_tv_power_on_off()
{
  ir_tx.Init();
  ir_tx.SendNEC(0x04, 0x08, 1);
  ir_tx.Stop();
    
  return proceed;
}

result menu_item_tv_channel_up()
{
  ir_tx.Init();
  ir_tx.SendNEC(0x04, 0x00, 1);
  ir_tx.Stop();
    
  return proceed;  
}

result menu_item_tv_channel_down()
{
  ir_tx.Init();
  ir_tx.SendNEC(0x04, 0x01, 1);
  ir_tx.Stop();
    
  return proceed;  
}

result menu_item_tv_volume_up()
{
  ir_tx.Init();
  ir_tx.SendNEC(0x04, 0x02, 1);
  ir_tx.Stop();
    
  return proceed;
}

result menu_item_tv_volume_down()
{
  ir_tx.Init();
  ir_tx.SendNEC(0x04, 0x03, 1);
  ir_tx.Stop();
    
  return proceed;
}

result menu_item_sound_status()
{
  return proceed;
}


result menu_item_battery_status()
{

  is_poll_BTN_SEL = !is_poll_BTN_SEL;
  
#ifdef DEBUG
  Serial.print("Battery: ");
  Serial.println(is_poll_BTN_SEL? "activated": "de-activated");
#endif

  if(is_poll_BTN_SEL){
    s_state = M_BATTERY;
  }
  else {
    s_state = M_DONE;
  }

  return proceed;  
}

result menu_item_about_status()
{

  is_poll_BTN_SEL = !is_poll_BTN_SEL;
  
  
#ifdef DEBUG
  Serial.print("About: ");
  Serial.println(is_poll_BTN_SEL? "activated": "de-activated");
#endif

  if(is_poll_BTN_SEL){
    s_state = M_ABOUT;
  }
  else {
    s_state = M_DONE;
  }

  return proceed;  

}

void set_torch_state();
void set_sound_state();


/**********************************************************************
 Setting up the menu sytem. This menu system comes from

  see https://github.com/neu-rah/ArduinoMenu/wiki/Menu-definition
 **********************************************************************/  


TOGGLE(is_torch_on,setTorchOnOff,"Torch: ",doNothing,noEvent,noStyle//,doExit,enterEvent,noStyle
  ,VALUE("On",true,set_torch_state,noEvent)
  ,VALUE("Off",false,set_torch_state,noEvent)
);

TOGGLE(is_sound_on,setSoundOnOff,"Sound: ",doNothing,noEvent,noStyle//,doExit,enterEvent,noStyle
  ,VALUE("On",true,set_sound_state,noEvent)
  ,VALUE("Off",false,set_sound_state,noEvent)
);



MENU(TVMenu, "TV menu", doNothing,noEvent,wrapStyle,
     OP("Power", menu_item_tv_power_on_off, enterEvent),
     OP("CH+", menu_item_tv_channel_up, enterEvent),
     OP("CH-", menu_item_tv_channel_down, enterEvent),     
     OP("Vol+", menu_item_tv_volume_up, enterEvent),
     OP("Vol-", menu_item_tv_volume_down, enterEvent),     
     EXIT("<BACK")
);



// good  
MENU(GenMenu, "General", doNothing,noEvent,wrapStyle,
     OP("Sound", menu_item_sound_status, enterEvent),
     OP("Battery", menu_item_battery_status, (eventMask)(focusEvent | blurEvent)),
     OP("About", menu_item_about_status, (eventMask)(focusEvent | blurEvent)),
     EXIT("<BACK")
     );


/*
//broke
MENU(GenMenu, "General", doNothing,noEvent,wrapStyle,
     OP("Battery", menu_item_battery_status, (eventMask)(focusEvent | blurEvent)),
     OP("About", menu_item_about_status, (eventMask)(focusEvent | blurEvent)),
     EXIT("<BACK")
     );

 */

// Main Menu

MENU(mainMenu,"MAIN menu",doNothing,noEvent,wrapStyle,
     SUBMENU(setTorchOnOff),
     SUBMENU(setSoundOnOff),
     OP("Thermal",menu_item_camera_status,(eventMask)(focusEvent | blurEvent)),
     OP("Sonic", menu_item_sonic_status,(eventMask)(focusEvent | blurEvent)),
     OP("Zapper", menu_item_zapper_status,(eventMask)(focusEvent | blurEvent)),
     OP("WIFI scan", menu_item_WIFI_status,(eventMask)(focusEvent | blurEvent)),
     SUBMENU(TVMenu),
     SUBMENU(GenMenu)
     //   EXIT("<Back")
);



#ifdef MENU_DEBUG
serialIn serial(Serial);
#endif

keyMap controlBtn_map[]={
 {BTN_SEL, defaultNavCodes[enterCmd].ch,INPUT_PULLDOWN} ,
 {BTN_UP, defaultNavCodes[upCmd].ch,INPUT_PULLUP} ,
 {BTN_DOWN, defaultNavCodes[downCmd].ch,INPUT_PULLDOWN}  ,
};
keyIn<3> controlBtns(controlBtn_map);

#ifdef MENU_DEBUG
MENU_INPUTS(in,&controlBtns,&serial);
#endif

MENU_INPUTS(in,&controlBtns);

#define GFX_WIDTH	135
#define GFX_HEIGHT	240

#define MAX_DEPTH 4
#define FONT_WIDTH 6
#define FONT_HEIGHT 12
#define TEXT_SCALE 1

// note MENU_OUTPUTS must have at least 2 items. Last item can be NONE
// See https://registry.platformio.org/libraries/neu-rah/ArduinoMenu%20library


// gfx, colors, width, height,
	     // the two vectors look like
	     // menu position and size {x, y, panel x size, panel y size (number of rows?)}
	     // submenu position and size


#ifndef MENU_DEBUG
MENU_OUTPUTS(out,MAX_DEPTH,
	     ADAGFX_OUT(gfx,colors,
		FONT_WIDTH*TEXT_SCALE,FONT_HEIGHT*TEXT_SCALE,
		{0,0,14,12},{16,1,14,8}),
	        NONE
	     );

#else
MENU_OUTPUTS(out,MAX_DEPTH,
	     ADAGFX_OUT(gfx,colors,FONT_WIDTH*TEXT_SCALE,FONT_HEIGHT*TEXT_SCALE,
		{0,0,14,8},{16,1,14,8}),
	        SERIAL_OUT(Serial)
	     );
#endif


NAVROOT(nav,mainMenu,MAX_DEPTH,in,out);

//when menu is suspended
result idle(menuOut& o,idleEvent e) {
  if (e==idling) {
    o.println(F("suspended..."));
    o.println(F("press [select]"));
    o.println(F("to continue"));
  }
  return proceed;
}


/**********************************************************************
 Setting up for FreeTOS
 **********************************************************************/  

TaskHandle_t master_task; // Master task runs on core 1
TaskHandle_t slave_task;  // slave task runs on core 0

QueueHandle_t m2s_queue;
QueueHandle_t s2m_queue;

void slave(void* p);
void audio_setup();


struct QueueMessage{
  MessageID id;
  int message;
};


/**********************************************************************
NAME

	ultrasonic_screwdriver is master program for the ultrasonic
	screwdriver.

		   
SYNOPSIS
	
	ultrasonic_screwdriver is the master program that communicates
	with the slave by issuing commands to it.

	The user interacts with the displayed menus controlled by the
	ultrasonic_screwdriver while most of the onboard devices are
	controlled by the the slave.

	The following are the onboard devices controlled by the
	ultrasonic_screwdriver:

	(1) IR remote
	(2) Sound
	
AUTHOR
	C.Y. Tan

REVISION
	$Revision$

SEE ALSO

**********************************************************************/


void setup() {

  // for the neopixel ring
  neopixel_ring.begin();
  neopixel_ring.setBrightness(50);
  neopixel_ring.show(); // initialize all pixels to off

  #ifdef DEBUG
    Serial.begin(115200);
    while(!Serial);
    Serial.println("Sonic Screwdriver button pressed test");
    Serial.flush();
  #endif  
  nav.idleTask=idle;//point a function to be used when menu is suspended

  //outGfx.usePreview=true;//reserve one panel for preview?
  //nav.showTitle=false;//show menu title?

  controlBtns.begin();

  // turn on backlite
  pinMode(TFT_BACKLITE, OUTPUT);
  digitalWrite(TFT_BACKLITE, HIGH);

  // Init ST7789 240x135. Note in Adafruit_ST7789.h, first argument is width, second is height
  gfx.init(GFX_WIDTH, GFX_HEIGHT);           
  gfx.setRotation(4);
  gfx.setTextSize(TEXT_SCALE);//test scalling
  gfx.setTextWrap(false);
  gfx.fillScreen(ST77XX_BLACK);
  gfx.setTextColor(ST77XX_RED,ST77XX_BLACK);

  // initialize for thermal camera

  displayPixelWidth =  GFX_HEIGHT / 32;
  displayPixelHeight = GFX_WIDTH / 32;
#ifdef DEBUG
  Serial.println("Adafruit MLX90640 Camera");
#endif  
  if (! mlx.begin(MLX90640_I2CADDR_DEFAULT, &Wire)) {
#ifdef DEBUG    
    Serial.println(F("MLX90640 not found!"));
#endif    
  }
#ifdef DEBUG  
  Serial.println("***Found Adafruit MLX90640");
#endif  
  
  mlx.setMode(MLX90640_CHESS);
  mlx.setResolution(MLX90640_ADC_18BIT);
  mlx.setRefreshRate(MLX90640_8_HZ);
  
  Wire.setClock(800000); // max 1 MHz doesn't work. Set to 800 kHz

  // initialize the ultrasonic

  // setup the ultrsonic enable/disable pin
  pinMode(ULTRASONIC_EN, OUTPUT);
  digitalWrite(ULTRASONIC_EN, LOW); // disable ultrasonic
  
  // setup the ultrasonic transducer
  #ifdef DEBUG  
  Serial.println("000Getting Serial1:");
  #endif
  Serial1.begin(9600, SERIAL_8N1); // for the ultrasonic
  while(!Serial1);

  #ifdef DEBUG
  Serial.println("Got Serial1");
  #endif

  // setup audio

  audio_setup();

  // initialize multi-core tasks on the two cores

  // make a master to slave queue

  m2s_queue = xQueueCreate(10, // queue depth
			   sizeof(struct QueueMessage));

  // and a slave to master queue
  s2m_queue = xQueueCreate(10, // queue depth
			   sizeof(struct QueueMessage));


  if(m2s_queue && s2m_queue){
    xTaskCreatePinnedToCore(master,"Master",10000,NULL,1,&master_task,1);
    delay(500);
    xTaskCreatePinnedToCore(slave,"Slave",10000,NULL,1,&slave_task,0);
    delay(500);
  }
}

void set_torch_state()
{
  QueueMessage m2s; // master to slave message
  
  m2s.id = M_TORCH;
  m2s.message = is_torch_on;
      
  xQueueSend(m2s_queue, &m2s, portMAX_DELAY);	      

  s_state = is_torch_on? M_TORCH: M_DONE;
}

void set_sound_state()
{
  s_state = is_sound_on? M_SOUND: M_DONE;
}


void poll_BTN_SEL(const int id){

  MessageID m_id = static_cast<MessageID>(id);
  QueueMessage m2s; // master to slave message
  QueueMessage s2m; // master to slave message    

  // check whether poll button is pressed
  if(is_poll_BTN_SEL){
    if(digitalRead(BTN_SEL) == HIGH){ // yes, button is pressed

      m2s.id = m_id;
      m2s.message = 1; // tell device to turn on	
      xQueueSend(m2s_queue, &m2s, portMAX_DELAY);
	
      // once I have a high here, I have to set is_poll_BTN_DESEL=true
      // so that I will now poll for deselection

      is_poll_BTN_SEL = false;
      is_poll_BTN_DESEL = true;

      // suspend the menu navigation
      nav.idleOn();
    }
  }

  if(is_poll_BTN_DESEL){

    if(digitalRead(BTN_SEL) == LOW){

      m2s.id = m_id;
      m2s.message = 0; // tell device to turn off	
      xQueueSend(m2s_queue, &m2s, portMAX_DELAY);

      // reset the poll flag
      is_poll_BTN_DESEL=false;
      is_poll_BTN_SEL=true; // continue waiting to make sure that I really exit the menu selection
      //      delay(100);

      // wait for the slave to tell me to restart
      s2m.id = M_BUSY;
      do{
	if(xQueueReceive(s2m_queue, &s2m, 10) == pdPASS){
	  if(s2m.id == M_DONE)
	    break;
	}
      } while(1);
      
      // tell the menu to restart
      nav.idleOff();

      // force a redraw of the menu
      mainMenu.dirty = true;
      nav.doOutput();
	
    }
    else {
      if(is_sound_on){
	copier.copy();
	if(sonicdriver_wave.isRunning() == false){
	  sonicdriver_wave.begin();
	}
      }
    }
  }  
}


void master(void* p)
{
#ifdef DEBUG
  Serial.print("Master is running on core ");
  Serial.println(xPortGetCoreID());
#endif

  while(1){

    nav.poll();//this device only draws when needed

    poll_BTN_SEL(s_state);

  } // while

}



void loop()
{}
  

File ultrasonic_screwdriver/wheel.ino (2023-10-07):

/***
  Wheel() is from the Arduino NeoPixel example.

https://github.com/adafruit/Adafruit_NeoPixel/blob/master/examples/strandtest_wheel/strandtest_wheel.ino

   Code is distributed under LGPL-3.0 license

   Copyright is held by Adafruit		       
***/

// Input a value 0 to 255 to get a color value.
// The colours are a transition r - g - b - back to r.
uint32_t Wheel(byte WheelPos) {
  WheelPos = 255 - WheelPos;
  if(WheelPos < 85) {
    return neopixel_ring.Color(255 - WheelPos * 3, 0, WheelPos * 3);
  }
  if(WheelPos < 170) {
    WheelPos -= 85;
    return neopixel_ring.Color(0, WheelPos * 3, 255 - WheelPos * 3);
  }
  WheelPos -= 170;
  return neopixel_ring.Color(WheelPos * 3, 255 - WheelPos * 3, 0);
}

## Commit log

2023-10-07 Added STL directory. Updated openscad/README.MD
    [cone.stl, endcap.stl, inner_lower_case.stl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]
2023-10-07 Added STL/README.MD. Updated README.MD and openscad/README.MD
2023-10-07 Updated STL/README.MD
2023-10-08 Updated README.MD, STL/README.MD. Added COPYING, LICENSE and README.MD in ultrasonic_screwdriver.
2023-10-08 Updated ultrasonic_screwdriver/README.MD
2023-10-08 Removed all traces of signature directory
2023-10-14 Added circuit directory which contains the schematic
2023-10-14 Updated circuit/README.MD
2023-10-14 Updated circuit/circuit.pdf
2023-10-17 Updated all the README.MD's. Added bom directory.
    [bom.ods]
2023-11-03 STL/cone.stl: increased IR LED hole size; circuit/circuit.pdf: updated IR LED resistor value and IR LED part; bom/bom.ods: updated IR LED part number; howto/assembly.pdf: Updated assembly instruction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
    [bom.ods, cone.stl]
2023-11-04 Updated openscad/sonic_case.scad: increased length of tail guide wings so that the open/close limits don't shear off the on/off switch tab; STL/tail_section.stl: the length of the guide wings were in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
    [sonic_case.scad, tail_section.stl]
2023-11-07 howto/assembly.pdf: Updated document to talk about arranging the wires and connectors so that the screwdriver can be flicked open.
2023-11-11 README.MD: Added words that will allow google to identify this distribution as a homemade DIY sonic screwdriver.
2023-11-19 howto/assembly.pdf: added photo with nearly assembled screwdriver on slide 21.
2024-01-04 Major update: Added ultrasonic screwdriver charging stand design in openscad, STL files, laser cutfiles and circuit. Updated BOM to reflect this addition. Updated directory structure to accommodate t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
    [bom.ods, cone.stl, endcap.stl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]
2024-01-05 Updated README's in laser_cut and openscad. Added STL/README.MD.
2024-01-16 Major update to charging circuit: The Ultrasonic Sonic Screwdriver can be charged by simply inserting it into the Charging Stand. No more unscrewing bottom cap to access charging cable+socket. The fo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
    [alignment_pegs.stl, bom.ods, slip_adapter_v2.stl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]
2024-01-16 Fixed a few typos in ther README.MD's in STL and circuit.
2024-01-16 Fixed typos in README's of STL
2024-01-16 Updated howto/assembly.pdf
2024-01-20 Improved design of alignment pegs in openscad/sonic_stand.scad. The result STL is stored in alignment_pegs.stl. Assembly manual in howto/assembly.pdf updated with this new improved design.
    [alignment_pegs.stl, sonic_stand.scad]
